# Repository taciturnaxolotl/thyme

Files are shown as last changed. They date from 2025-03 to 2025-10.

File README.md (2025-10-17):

# The thyme keyboard

blueprint

> [!NOTE]
> If you want to build this yourself then go grab the files from the latest release!

## BOM

| Part | Quantity | Price | Link | Description | Notes |
| --- | --- | --- | --- | --- | --- |
| PCB | 1 | `$15.70` | [JLCPCB](https://jlcpcb.com) | 2-layer, 1.6mm, black, leaded Hasl | I wanted to get ENIG but that bumped the price by `$20` |
| Total `$15.70` + `$13.04` shipping | | | | | |
| | | | | | |
| Choc v1 switches | 50 | `$25.00` | [Chosfox](https://chosfox.com/products/kailh-chocs?variant=42514648006850) | pink variant: `20+-5 gf` linear | `$0.50` per switch |
| Choc PG1350 | 50 | `$7.25`  | [Chosfox](https://chosfox.com/products/kailh-choc-switch-1350-hot-swap-sockets) | hot swap sockets | `$0.145` per socket |
| 1u keycaps | 40 | `$14.00` | [Chosfox](https://chosfox.com/collections/low-profile-keycaps/products/chocfox-cfx-choc-keycaps) | White PBT low profile | `$0.35` per keycap |
| 1u homing keycaps | 2 | `$0.80`  | [Chosfox](https://chosfox.com/collections/low-profile-keycaps/products/chocfox-cfx-choc-keycaps) | White PBT low profile | `$0.40` per keycap |
| 1.5u keycaps | 2 | `$1.65`  | [Chosfox](https://chosfox.com/collections/low-profile-keycaps/products/chocfox-cfx-choc-keycaps) | White PBT low profile | `$0.83` per keycap |
| Total cost: `$48.70` + `$8` shipping | | | | average of `$0.37` per keycap | |
| | | | | | |
| SuperMini NRF52840 (Nice!Nano footprint) | 2 | `$8.08`  | [AliExpress](https://www.aliexpress.us/item/3256805848952479.html) | Wireless Microcontroller | `$4.04` per MCU |
| 301230 3.7V 110mAh LiPo Battery | 2 | `$7.50`  | [AliExpress](https://www.aliexpress.us/item/2255799987926232.html) | the non jst ones are cheaper but the crimper is 60 bucks and there is no way im buying that | `$3.75` per battery |
| Diodes | 42 | `$0.99`  | [Aliexpress](https://www.aliexpress.us/item/2255800939822415.html) | 1N4148 | `$0.01` per diode |
| Machine Pins | 1 | `$0.99`  | [AliExpress](https://www.aliexpress.us/item/3256805556329561.html) | 26x2 needed to socket the two MCUs | comes in a 100 pack of 4 per header |
| Total cost: `$14.10` + `$6.52` shipping | | | | | |
| | | | | | |
| Power Switch | 4 | `$0.39`  | [DigiKey](https://www.digikey.com/en/products/detail/same-sky-formerly-cui-devices/SLW-1277744-3A-N-D/24399208) | added an extra switch for each side as backup | `$0.10` per switch |
| JST PH 2.0mm 2-pin Connector | 4 | `$0.40`  | [DigiKey](https://www.digikey.com/en/products/detail/jst-sales-america-inc/S2B-PH-K-S/926626) | | `$0.10` per connector |
| Total cost: `$1.96` + `$8.15` tarrif/sales tax/shipping | i cant find good matches for these on ali and shipping is ridiculous rn as well | | | | |
| | | | |
| Machine Sockets 2.54mm | 1 | `$7.35`  | [Amazon](https://www.amazon.com/dp/B08Y8RB4BH) | 26x2 needed to socket the two MCUs | comes in a 10 pack of 40x1 rows |

Total cost: `$123.52`

### Shipping / Tax / Tariffs / Per store shopping list

| Store | Shipping | Subtotal | Total | Items |
| --- | --- | --- | --- | --- |
| AliExpress | `$6.52` | `$14.20` | `$20.62` | 2x SuperMini NRF52840, Machine Pins, 2x LiPo Battery, 42x diodes |
| DigiKey | `$8.15` (tarrifs and tax too) | `$1.96`  | `$10.11` | 4x Power Switch, 4x JST Connector |
| Chosfox | `$8` | `$48.70` | `$56.70` | 50x Choc v1 switches, 40x 1u keycaps, 2x 1u homing keycaps, 2x 1.5u keycaps |
| JLCPCB | `$13.04` | `$15.70` | `$28.74` | 1x PCB |
| Amazon | `$0` | `7.35` | `$7.35`  | machine sockets |

## Schematics

schematic

pcb

## Build Notes

Panelization is the most annoying bit of this whole process. I was able to finally get it work work by using [`kikit`](https://yaqwsx.github.io/KiKit/latest/installation/intro/) to generate rails and tabs.

```bash
kikit panelize \
    --layout 'grid; rows: 1; cols: 1; space: 3mm;' \
    --tabs 'fixed; width: 3mm; vcount: 8;' \
    --cuts 'mousebites; drill: 0.5mm; spacing: 1mm; offset: 0.2mm; prolong: 0.5mm;' \
    --framing 'railstb; width: 5mm; space: 3mm; chamfer: 1mm;' \
    --tooling '3hole; hoffset: 2.5mm; voffset: 2.5mm; size: 1.5mm;' \
    --fiducials '3fid; hoffset: 5mm; voffset: 2.5mm; coppersize: 2mm; opening: 1mm;' \
    --post 'millradius: 1mm;' \
    --text 'simple; text: "THYME v1.14"; anchor: mt; voffset: 2mm;' \
    --text2 'simple; text: Created on {date} JLC Order: JLCJLCJLC; anchor: mb; voffset: -2.5mm; hjustify: center; vjustify: center;' \
    thyme.kicad_pcb panelization/panelized.kicad_pcb
```

panelized

Firmware is `zmk` and is maintained in the submodule [/zmk](https://github.com/taciturnaxolotl/thyme-module). The latest firmware build can be grabbed from [nightly.link/taciturnaxolotl/thyme-module/workflows/build](https://nightly.link/taciturnaxolotl/thyme-module/workflows/build/main) as a zip containing the left and right half `uf2` files.

The case was made in onshape and is available in [this document](https://cad.onshape.com/documents/eb30178d0af4291efc746ab6/w/0d165c7d0bf8d717a9598c9f/e/3dd4b0baac9c9ef14c8041ba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). The case is made of PLA and printed on an A1 mini. It is likely to change quite a bit once I get my pcb assembled and can fit test stuff. Evenentually I would like to add a top plate that attaches to the bottom with magnets and mill the whole case out of aluminum.

A major tool that helped with the research and organization of my thoughts was my [figjam board](https://www.figma.com/board/wyCQS9SeIG2Sutu5v6OT2m/thyme---split-mech-keyboard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)! I used it to keep track of all the resources I found and what parts I wanted to use. Once I got to actually picking specific parts I moved that to the bom table above.

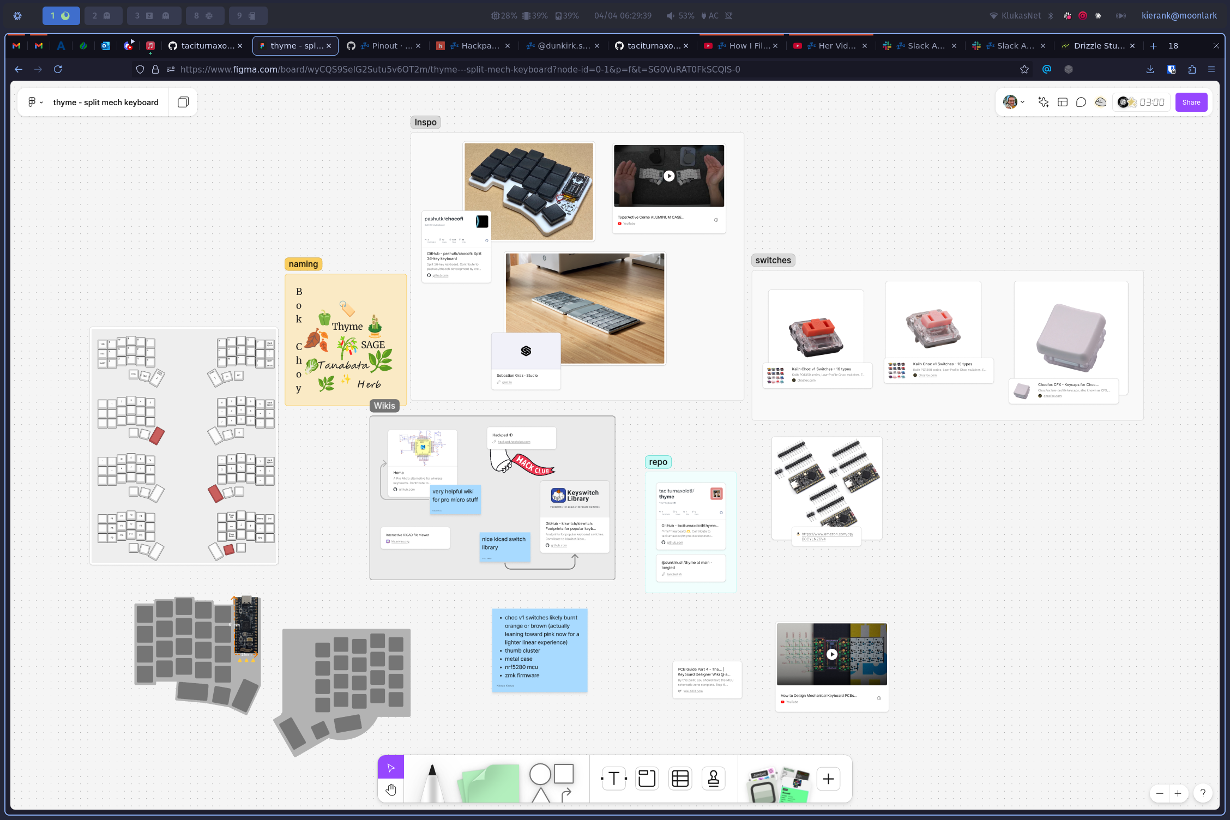
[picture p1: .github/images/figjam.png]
figjam board


<p align="center">
	
</p>

<p align="center">
	<i><code>&copy 2025-present <a href="https://github.com/taciturnaxolotl">Kieran Klukas</a></code></i>
</p>

<p align="center">
	
</p>

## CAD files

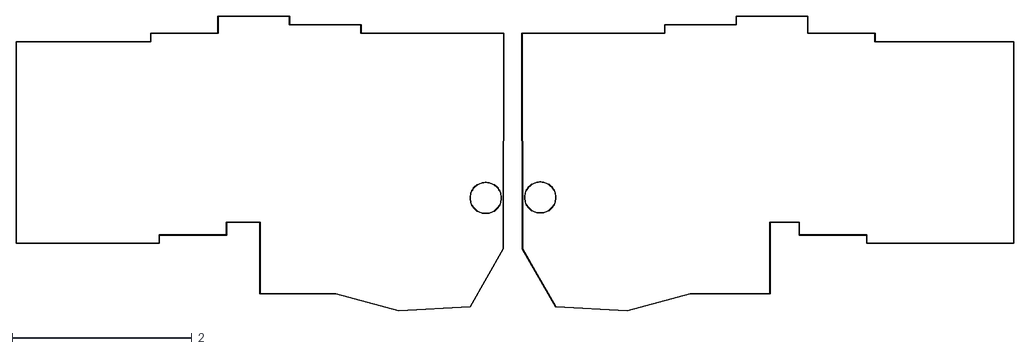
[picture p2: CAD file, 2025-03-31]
kicad/thyme-Edge_Cuts.dxf
11.1 x 3.27

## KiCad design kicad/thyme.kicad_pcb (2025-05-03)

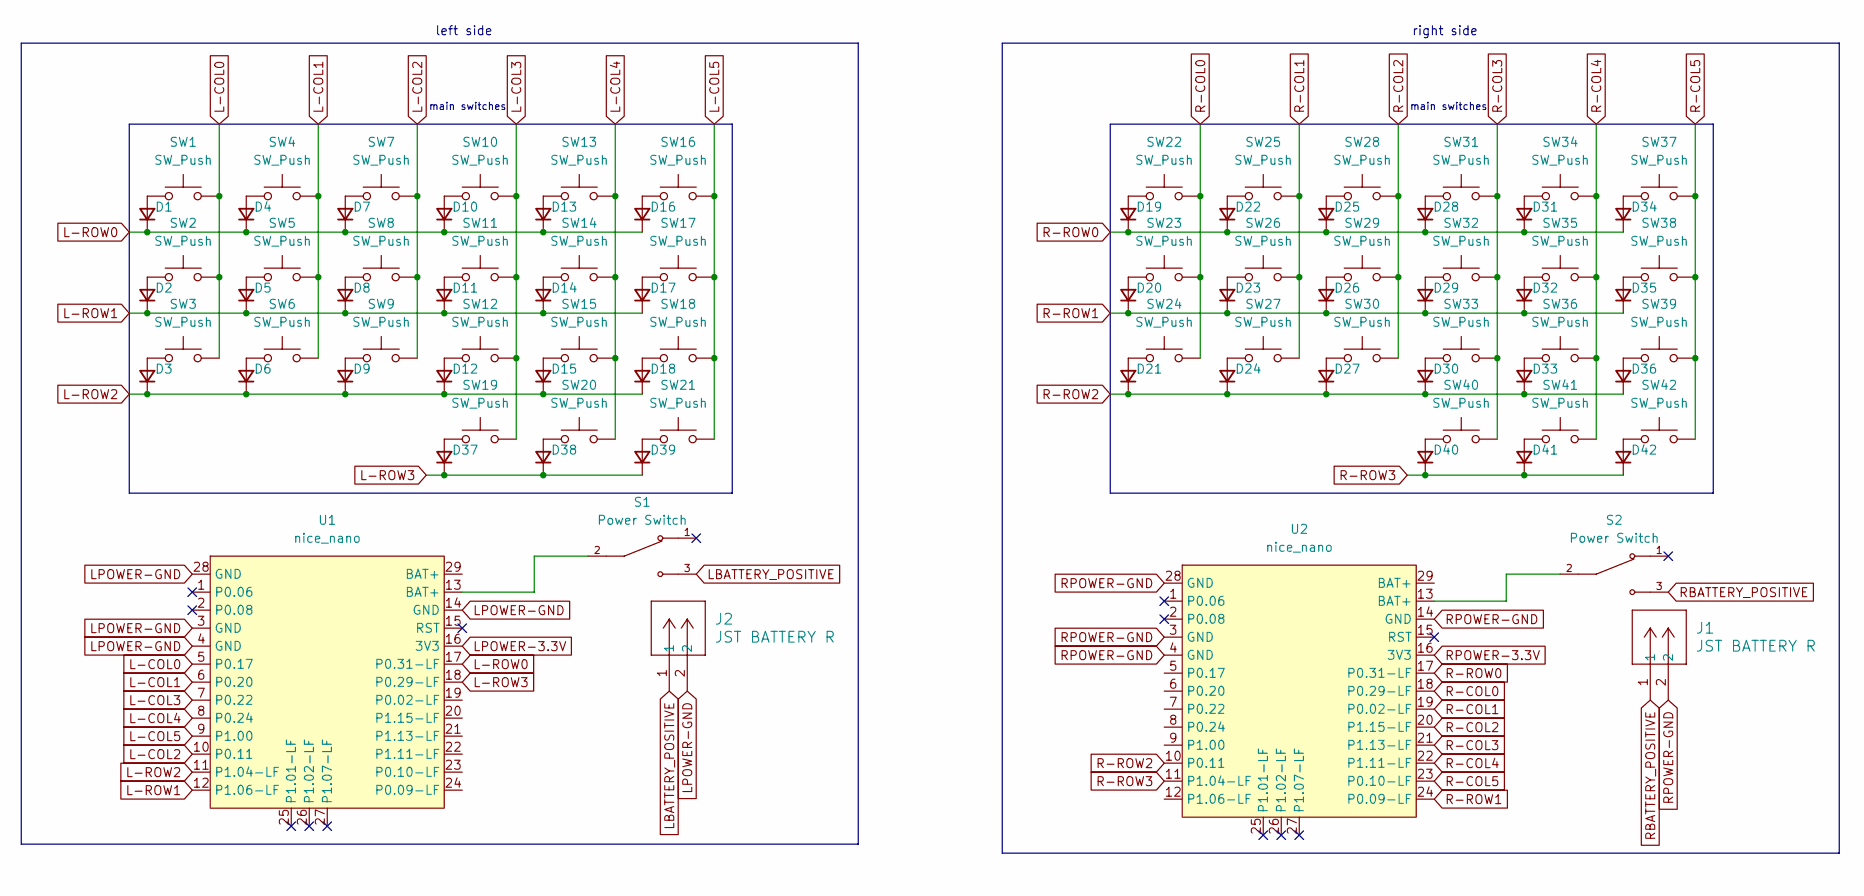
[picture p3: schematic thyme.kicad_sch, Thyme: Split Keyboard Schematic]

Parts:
D1, D2, D3, D4, D5, D6, D7, D8, D9, D10, D11, D12, D13, D14, D15, D16, D17, D18, D19, D20, D21, D22, D23, D24, D25, D26, D27, D28, D29, D30, D31, D32, D33, D34, D35, D36, D37, D38, D39, D40, D41, D42: D_Small; D_DO-35_SOD27_P7.62mm_Horizontal
J1, J2: JST BATTERY R; CONN_S2B-PH-K-S_JST
S1, S2: Power Switch; SW_SLW-1277744-3A-N-D; PARTREV 1.01
SW1, SW2, SW3, SW4, SW5, SW6, SW7, SW8, SW9, SW10, SW11, SW12, SW13, SW14, SW15, SW16, SW17, SW18, SW19, SW20, SW21, SW22, SW23, SW24, SW25, SW26, SW27, SW28, SW29, SW30, SW31, SW32, SW33, SW34, SW35, SW36, SW37, SW38, SW39, SW40, SW41, SW42: SW_Push; SW_Hotswap_Kailh_Choc_V1V2_1.00u
U1, U2: nice_nano; SuperMini NRF52840

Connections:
L-COL0: SW1.2, SW2.2, SW3.2, U1.5 (P0.17)
L-COL1: SW4.2, SW5.2, SW6.2, U1.6 (P0.20)
L-COL2: SW7.2, SW8.2, SW9.2, U1.10 (P0.11)
L-COL3: SW10.2, SW11.2, SW12.2, SW19.2, U1.7 (P0.22)
L-COL4: SW13.2, SW14.2, SW15.2, SW20.2, U1.8 (P0.24)
L-COL5: SW16.2, SW17.2, SW18.2, SW21.2, U1.9 (P1.00)
L-ROW0: D1.1 (K), D4.1 (K), D7.1 (K), D10.1 (K), D13.1 (K), D16.1 (K), U1.17 (P0.31-LF)
L-ROW1: D2.1 (K), D5.1 (K), D8.1 (K), D11.1 (K), D14.1 (K), D17.1 (K), U1.12 (P1.06-LF)
L-ROW2: D3.1 (K), D6.1 (K), D9.1 (K), D12.1 (K), D15.1 (K), D18.1 (K), U1.11 (P1.04-LF)
L-ROW3: D37.1 (K), D38.1 (K), D39.1 (K), U1.18 (P0.29-LF)
LBATTERY_POSITIVE: J2.1, S1.3
LPOWER-3.3V: U1.16 (3V3)
LPOWER-GND: J2.2, U1.3 (GND), U1.4 (GND), U1.14 (GND), U1.28 (GND)
unnamed: D1.2 (A), SW1.1
unnamed: D2.2 (A), SW2.1
unnamed: D3.2 (A), SW3.1
unnamed: D4.2 (A), SW4.1
unnamed: D5.2 (A), SW5.1
unnamed: D6.2 (A), SW6.1
unnamed: D7.2 (A), SW7.1
unnamed: D8.2 (A), SW8.1
unnamed: D9.2 (A), SW9.1
unnamed: D10.2 (A), SW10.1
unnamed: D11.2 (A), SW11.1
unnamed: D12.2 (A), SW12.1
unnamed: D13.2 (A), SW13.1
unnamed: D14.2 (A), SW14.1
unnamed: D15.2 (A), SW15.1
unnamed: D16.2 (A), SW16.1
unnamed: D17.2 (A), SW17.1
unnamed: D18.2 (A), SW18.1
unnamed: D19.2 (A), SW22.1
unnamed: D20.2 (A), SW23.1
unnamed: D21.2 (A), SW24.1
unnamed: D22.2 (A), SW25.1
unnamed: D23.2 (A), SW26.1
unnamed: D24.2 (A), SW27.1
unnamed: D25.2 (A), SW28.1
unnamed: D26.2 (A), SW29.1
unnamed: D27.2 (A), SW30.1
unnamed: D28.2 (A), SW31.1
unnamed: D29.2 (A), SW32.1
unnamed: D30.2 (A), SW33.1
unnamed: D31.2 (A), SW34.1
unnamed: D32.2 (A), SW35.1
unnamed: D33.2 (A), SW36.1
unnamed: D34.2 (A), SW37.1
unnamed: D35.2 (A), SW38.1
unnamed: D36.2 (A), SW39.1
unnamed: D37.2 (A), SW19.1
unnamed: D38.2 (A), SW20.1
unnamed: D39.2 (A), SW21.1
unnamed: D40.2 (A), SW40.1
unnamed: D41.2 (A), SW41.1
unnamed: D42.2 (A), SW42.1
unnamed: S1.2, U1.13 (BAT+)
unnamed: S2.2, U2.13 (BAT+)
R-COL0: SW22.2, SW23.2, SW24.2, U2.18 (P0.29-LF)
R-COL1: SW25.2, SW26.2, SW27.2, U2.19 (P0.02-LF)
R-COL2: SW28.2, SW29.2, SW30.2, U2.20 (P1.15-LF)
R-COL3: SW31.2, SW32.2, SW33.2, SW40.2, U2.21 (P1.13-LF)
R-COL4: SW34.2, SW35.2, SW36.2, SW41.2, U2.22 (P1.11-LF)
R-COL5: SW37.2, SW38.2, SW39.2, SW42.2, U2.23 (P0.10-LF)
R-ROW0: D19.1 (K), D22.1 (K), D25.1 (K), D28.1 (K), D31.1 (K), D34.1 (K), U2.17 (P0.31-LF)
R-ROW1: D20.1 (K), D23.1 (K), D26.1 (K), D29.1 (K), D32.1 (K), D35.1 (K), U2.24 (P0.09-LF)
R-ROW2: D21.1 (K), D24.1 (K), D27.1 (K), D30.1 (K), D33.1 (K), D36.1 (K), U2.10 (P0.11)
R-ROW3: D40.1 (K), D41.1 (K), D42.1 (K), U2.11 (P1.04-LF)
RBATTERY_POSITIVE: J1.1, S2.3
RPOWER-3.3V: U2.16 (3V3)
RPOWER-GND: J1.2, U2.3 (GND), U2.4 (GND), U2.14 (GND), U2.28 (GND)

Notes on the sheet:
left side
main switches
right side

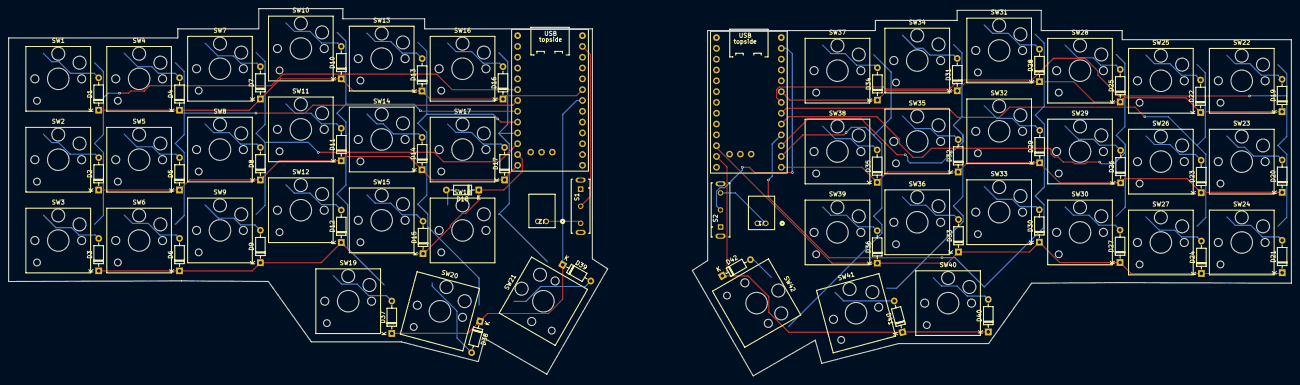
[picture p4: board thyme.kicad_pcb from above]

Board: 2 copper layers, 301.4 x 86.3 mm, 90 parts (0 on the bottom side), 68 nets.

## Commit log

2025-03-25 feat: add schematic v0.1
    [thyme.kicad_pcb, thyme.kicad_sch]
2025-03-28 feat: add the jst power connections and connect nets
    [thyme.kicad_sch]
2025-03-28 bug: fix row 5 being unconnected
    [thyme.kicad_pcb, thyme.kicad_sch]
2025-03-28 chore: split power into left and right and add no connects
    [thyme.kicad_pcb, thyme.kicad_sch]
2025-03-30 chore: move around footprints
    [thyme.kicad_pcb]
2025-03-30 feat: align key switches in pcb
    [thyme.kicad_pcb]
2025-03-31 feat: arrange switches and add edge cuts
    [thyme.kicad_pcb, thyme.kicad_sch]
2025-03-31 feat: place diodes
    [thyme.kicad_pcb]
2025-03-31 feat: add new jst connector and route the board
    [thyme.kicad_pcb, thyme.kicad_sch]
2025-03-31 feat: add 3d models
    [thyme.kicad_pcb]
2025-03-31 feat: add images
    [thyme.kicad_pcb]
2025-03-31 feat: move jst to top for machine pins
    [thyme-Edge_Cuts.dxf, thyme.kicad_pcb]
2025-03-31 feat: move to jst tht connector and new switches
    [thyme.kicad_pcb, thyme.kicad_sch]
2025-03-31 feat: add panelization
    [panelized.kicad_pcb, thyme.kicad_pcb]
2025-03-31 feat: add panelization schematic and instructions
2025-04-01 chore: move jst to allow room for 1.75u keycaps
    [panelized.kicad_pcb, thyme.kicad_pcb]
2025-04-01 feat: add bom
2025-04-01 docs: organize bom
2025-04-04 feat: use same cutout for both halves
    [panelized.kicad_pcb, thyme.kicad_pcb]
2025-04-04 [ImgBot] Optimize images
    *Total -- 4,728.86kb -> 3,465.49kb (26.72%)
    /.github/images/schematic.svg -- 2,261.43kb -> 1,586.05kb (29.86%)
    /.github/images/pcb.svg -- 2,460.69kb -> 1,872.77kb (23.89%)
    /.github/images/tanabata.svg -- 6.75kb -> 6.67kb (1.24%)
2025-04-04 feat: add cad
    [thyme_case_Left.step, thyme_case_Right.step]
2025-04-04 feat: use another row instead of col 7
    [panelized.kicad_pcb, thyme.kicad_pcb, thyme.kicad_sch]
2025-04-10 feat: redesign edge cuts and key spacing
    [panelized.kicad_pcb, thyme.kicad_pcb, thyme.kicad_sch]
2025-04-10 feat: update cad design for v16
    [thyme_case_Left.step, thyme_case_Right.step]
2025-04-10 feat: add hot swap sockets
    [panelized.kicad_pcb, thyme.kicad_pcb, thyme.kicad_sch]
2025-04-10 docs: add hot swap sockets
2025-05-03 feat: remove uncessessary bits of footprint
    [panelized.kicad_pcb, thyme.kicad_pcb]
2025-10-16 chore: update bom
    [thyme_case_Left.step, thyme_case_Right.step]
2025-10-16 docs: update bom again
2025-10-17 docs: make bom cheaper
2025-11-12 feat: move to 6 connectors and remove silkscreen lables
